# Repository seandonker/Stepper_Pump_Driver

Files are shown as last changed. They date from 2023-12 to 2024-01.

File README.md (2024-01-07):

# Stepper Pump Driver
Kicad design files and C code (adding soon) for a small PCB to control a peristaltic stepper motor pump (or any single low current bipolar stepper really).

Rendered_Board

This project was created as a cheaper alternative for fully integrated peristaltic pump solutions that tend to cost $200 or more. These stand alone units use pumps that can be had for ~$50 and lack the full programmability that this project offers through Arduino coding. While this project was meant to be used for controllings pumps (like 
[this pump here](https://www.amazon.ca/Peristaltic-Stepper-Kamoer-KPHM400-Variable/dp/B097XXJ1XD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)), it can be used for a variety of purposes where some adjustments need to be made on the fly by someone who may not know how to program/flash the arduino. This is why the design features a potentiometer and a button to change things like speed or on-time intervals. 

Component Requirements
---------------------
Apart from the provided BOM and Digikey list. The system needs a power supply, stepper motor, and the display purchased separately. 
* The power supply jack is a standard 2.1mmID x 5.5mmOD size and the supply should be rated for 12v and 3 amps or greater. 
* Bipolar stepper motor (currently selected plug socket is for a JST XHP-4 and max motor current is 1A RMS)
* The OLED display is a common 0.91" I2C with a SSD1306 chipset used in Arduino projects
* The USB differential lines were designed for a 1mm thick, 1oz top and bottom, 2-layer board (I ordered from JLPCB)

[Digikey List](https://www.digikey.ca/en/mylists/list/M6HG9QW1PJ)

Programming and Power
---------------------
The board uses the common ATMEGA328P found in some standard models of Arduinos as this allows for the use of the libraries created for the OLED screen saving a lot of time and effort. 
There is an in-circuit-serial-programming (ICSP) header to burn the arduino bootloader if the chips were purchased blank from a distributor. Then you can either continue using the header for programming or use the USB port. For the USB to work however, the USB host controller chip (FT230X) needs to be programmed through the FT_PROG utility to change one output signal of the device. Please check the schematic and the datasheet of the chip for more details. The motor driver can only be powered from the 12v source but the MCU can run from either the USB or the 12v adapter allowing for programming without the 12v supply. Both can be plugged in simultaneously without issue for serial communication for data logging or other purposes. 

Future Improvements
------------------
I would like to use a 5v regulator capable of higher input voltages (or use a DC-DC converter) so the motor controller is capable of higher speeds. With that, it would be better if the PCB has 2oz copper layers for more current and better heat sinking capabilities. This would likely require a 4-layer board however as the USB trace impedance would become hard to design. A rotary encoder would be a much better method of input too, and would be easy to implement in hardware with a 4-layer board (but would require slightly more programming).

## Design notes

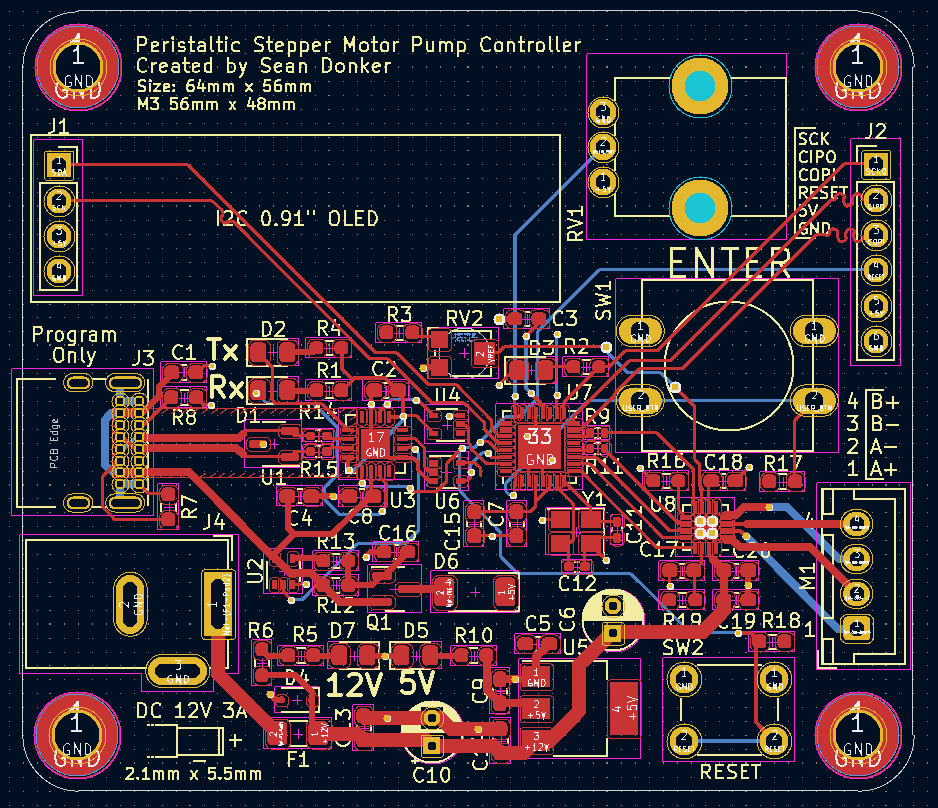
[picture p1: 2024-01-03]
PCB_Layout.png

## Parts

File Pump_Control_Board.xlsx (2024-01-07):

Source: | C:\Users\seand\Documents\KiCad\Projects\Stepper_Pump_Driver-main\Stepper_Pump_Driver-main\KiCad Files\Pump_Control_Board.kicad_sch
Date: | 2024-01-06 15:06
Tool: | Eeschema 7.0.7
Generator: | C:\Program Files\KiCad\7.0\bin\scripting\plugins/bom_csv_grouped_by_value.py
Component Count: | 70
Collated Components:
Item | Qty | Reference(s) | Value | LibPart | Footprint | Link
1 | 9 | C1, C2, C3, C7, C8, C16, C17, C18, C20 | 0.1uF | Device:C | Capacitor_SMD:C_0603_1608Metric_Pad1.08x0.95mm_HandSolder | https://www.digikey.ca/en/products/detail/samsung-electro-mechanics/CL10B104KB8NNWC/3887593
2 | 7 | C4, C5, C9, C13, C14, C15, C19 | 2.2uF | Device:C | Capacitor_SMD:C_0603_1608Metric_Pad1.08x0.95mm_HandSolder | https://www.digikey.ca/en/products/detail/samsung-electro-mechanics/CL10A225KL8NNNC/5961210
3 | 2 | C6, C10 | 100uF | Device:C_Polarized | Capacitor_THT:CP_Radial_D4.0mm_P2.00mm | https://www.digikey.ca/en/products/detail/rubycon/25PX100MEFC5X11/3134180?s=N4IgTCBcDaIIxwBwE4C0cxgCwgLoF8g
4 | 2 | C11, C12 | 15pF | Device:C_Small | Capacitor_SMD:C_0402_1005Metric_Pad0.74x0.62mm_HandSolder | https://www.digikey.ca/en/products/detail/samsung-electro-mechanics/CL05C150JB5NNNC/3886837
5 | 1 | D1 | RX_LED | Device:LED | LED_SMD:LED_0805_2012Metric_Pad1.15x1.40mm_HandSolder | https://www.digikey.ca/en/products/detail/harvatek-corporation/B1701USD-20D000114U1930/16671746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
6 | 1 | D2 | TX_LED | Device:LED | LED_SMD:LED_0805_2012Metric_Pad1.15x1.40mm_HandSolder | https://www.digikey.ca/en/products/detail/harvatek-corporation/B1701USD-20D000114U1930/16671746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
7 | 1 | D3 | MCU_LED | Device:LED | LED_SMD:LED_0805_2012Metric_Pad1.15x1.40mm_HandSolder | https://www.digikey.ca/en/products/detail/harvatek-corporation/B1701USD-20D000114U1930/16671746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
8 | 1 | D4 | SD15-01 | Device:D_Zener | Diode_SMD:D_SOD-323F | https://www.digikey.ca/en/products/detail/littelfuse-inc/SD15-01FTG/5019597?s=N4IgTCBcDaIGIDYAsSDMBhAKiAugXyA
9 | 1 | D5 | 5V_LED | Device:LED | LED_SMD:LED_0805_2012Metric_Pad1.15x1.40mm_HandSolder | https://www.digikey.ca/en/products/detail/harvatek-corporation/B1701USD-20D000114U1930/16671746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
10 | 1 | D6 | PMEG3030 | Device:D_Schottky | Diode_SMD:D_SOD-128 | https://www.digikey.ca/en/products/detail/nexperia-usa-inc/PMEG3030BEP-115/2228691
11 | 1 | D7 | 12V_LED | Device:LED | LED_SMD:LED_0805_2012Metric_Pad1.15x1.40mm_HandSolder | https://www.digikey.ca/en/products/detail/harvatek-corporation/B1701USD-20D000114U1930/16671746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
12 | 1 | F1 | Fuse | Device:Fuse | Fuse:Fuse_1206_3216Metric_Pad1.42x1.75mm_HandSolder | https://www.digikey.ca/en/products/detail/bel-fuse-inc/C1F-5/4968257
13 | 4 | H1, H2, H3, H4 | MountingHole_Pad | Mechanical:MountingHole_Pad | MountingHole:MountingHole_3.2mm_M3_ISO7380_Pad_TopBottom
14 | 1 | J1 | OLED | Connector_Generic:Conn_01x04 | Connector_PinSocket_2.54mm:PinSocket_1x04_P2.54mm_Vertical
15 | 1 | J2 | ICP Header | Connector_Generic:Conn_01x06 | Connector_PinHeader_2.54mm:PinHeader_1x06_P2.54mm_Vertical | https://www.digikey.ca/en/products/detail/sullins-connector-solutions/PPPC061LFBN-RC/810178
16 | 1 | J3 | USB_C_Receptacle_USB2.0 | Connector:USB_C_Receptacle_USB2.0 | Connector_USB:USB_C_Receptacle_GCT_USB4085 | https://www.digikey.ca/en/products/detail/gct/USB4085-GF-A/9859662?s=N4IgTCBcDaIKoGUBCAWADADgKwgLoF8g
17 | 1 | J4 | Jack | Connector:Barrel_Jack_Switch_Pin3Ring | Connector_BarrelJack:BarrelJack_GCT_DCJ200-10-A_Horizontal | https://www.digikey.ca/en/products/detail/gct/dcj200-10-a-k1-k/9859579
18 | 1 | M1 | Stepper_Motor_bipolar | Motor:Stepper_Motor_bipolar | Connector_JST:JST_XH_B4B-XH-A_1x04_P2.50mm_Vertical | https://www.digikey.ca/en/products/detail/jst-sales-america-inc/B4B-XH-A/1651047
19 | 1 | Q1 | SSM3J328R | Transistor_FET:AO3401A | Package_TO_SOT_SMD:SOT-23 | https://www.digikey.ca/en/products/detail/toshiba-semiconductor-and-storage/SSM3J328R-LF/2753199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
20 | 2 | R1, R4 | 270R | Device:R | Resistor_SMD:R_0603_1608Metric_Pad0.98x0.95mm_HandSolder | https://www.digikey.ca/en/products/detail/yageo/RC0603FR-13270RL/14286751
21 | 1 | R2 | 470R | Device:R | Resistor_SMD:R_0603_1608Metric_Pad0.98x0.95mm_HandSolder | https://www.digikey.ca/en/products/detail/yageo/RC0603FR-13470RL/13694077
22 | 1 | R3 | 10K | Device:R | Resistor_SMD:R_0603_1608Metric_Pad0.98x0.95mm_HandSolder | https://www.digikey.ca/en/products/detail/yageo/RC0603FR-0710KL/726880
23 | 1 | R5 | 1K | Device:R | Resistor_SMD:R_0603_1608Metric_Pad0.98x0.95mm_HandSolder | https://www.digikey.ca/en/products/detail/yageo/RC0603FR-0710KL/726880
24 | 2 | R6, R10 | 1K | Device:R | Resistor_SMD:R_0603_1608Metric_Pad0.98x0.95mm_HandSolder | https://www.digikey.ca/en/products/detail/yageo/RC0603FR-0710KL/726880
25 | 2 | R7, R8 | 5.1k | Device:R | Resistor_SMD:R_0603_1608Metric_Pad0.98x0.95mm_HandSolder | https://www.digikey.ca/en/products/detail/yageo/RC0603FR-135K1L/14008317
26 | 2 | R9, R11 | 0R | Device:R | Resistor_SMD:R_0402_1005Metric
27 | 1 | R12 | 91k | Device:R | Resistor_SMD:R_0603_1608Metric_Pad0.98x0.95mm_HandSolder | https://www.digikey.ca/en/products/detail/yageo/RC0603FR-0791KL/727428
28 | 1 | R13 | 1k | Device:R | Resistor_SMD:R_0603_1608Metric_Pad0.98x0.95mm_HandSolder | https://www.digikey.ca/en/products/detail/yageo/RC0603FR-0710KL/726880
29 | 2 | R14, R15 | 27R | Device:R | Resistor_SMD:R_0402_1005Metric_Pad0.72x0.64mm_HandSolder | https://www.digikey.ca/en/products/detail/yageo/RC0402FR-0727RL/5280946
30 | 2 | R16, R19 | 47K | Device:R | Resistor_SMD:R_0603_1608Metric_Pad0.98x0.95mm_HandSolder | https://www.digikey.ca/en/products/detail/yageo/RC0603JR-1347KL/13694120
31 | 2 | R17, R18 | 10k | Device:R | Resistor_SMD:R_0603_1608Metric_Pad0.98x0.95mm_HandSolder | https://www.digikey.ca/en/products/detail/yageo/RC0603FR-0710KL/726880
32 | 1 | RV1 | POT | Device:R_Potentiometer | Potentiometer_THT:Potentiometer_Bourns_PTV09A-1_Single_Vertical | https://www.digikey.ca/en/products/detail/bourns-inc/PTV09A-4220U-B103/3781152
33 | 1 | RV2 | Trimmer_10K | Device:R_Potentiometer | Potentiometer_SMD:Potentiometer_Bourns_TC33X_Vertical | https://www.digikey.ca/en/products/detail/bourns-inc/TC33X-2-103E/612858
34 | 1 | SW1 | SW_USER | Switch:SW_Push | Button_Switch_THT:SW_PUSH-12mm | https://www.digikey.ca/en/products/detail/cui-devices/TS14-1212-43-BK-160-SCR-D/16562768
35 | 1 | SW2 | SW_RESET | Switch:SW_Push | Button_Switch_THT:SW_PUSH_6mm | https://www.digikey.ca/en/products/detail/cui-devices/TS02-66-50-BK-260-SCR-D/15634296
36 | 1 | U1 | ESDALD05 | Donker_Custom:ESDALD05 | Package_TO_SOT_SMD:SOT-23-3 | https://www.digikey.ca/en/products/detail/ween-semiconductors/ESDALD05UE2X/15775762
37 | 3 | U2, U4, U6 | SN74LV1T34DCK | Logic_LevelTranslator:SN74LV1T34DCK | Package_TO_SOT_SMD:SOT-353_SC-70-5 | https://www.digikey.ca/en/products/detail/texas-instruments/SN74LV1T34DCKR/4555576
38 | 1 | U3 | FT230XQ | Interface_USB:FT230XQ | Package_DFN_QFN:QFN-16-1EP_4x4mm_P0.65mm_EP2.1x2.1mm | https://www.digikey.ca/en/products/detail/ftdi-future-technology-devices-international-ltd/FT230XQ-R/3029142
39 | 1 | U5 | LM1117DT-5.0 | Regulator_Linear:LM1117DT-5.0 | Package_TO_SOT_SMD:SOT-223 | https://www.digikey.ca/en/products/detail/onsemi/NCP1117LPST50T3G/2194022
40 | 1 | U7 | ATmega328P-M | MCU_Microchip_ATmega:ATmega328P-M | Package_DFN_QFN:QFN-32-1EP_5x5mm_P0.5mm_EP3.1x3.1mm | https://www.digikey.ca/en/products/detail/microchip-technology/ATMEGA328PB-MU/5638814
41 | 1 | U8 | DRV8428_WQFN | Donker_Custom:DRV8428_WQFN | Package_DFN_QFN:WQFN-16-1EP_3x3mm_P0.5mm_EP1.68x1.68mm | https://www.digikey.ca/en/products/detail/texas-instruments/DRV8428RTER/13687809
42 | 1 | Y1 | 16MHz | Device:Crystal_GND24_Small | Crystal:Crystal_SMD_3225-4Pin_3.2x2.5mm | https://www.digikey.ca/en/products/detail/raltron-electronics/RH100-16-000-12-1010-EXT-TR/10272690

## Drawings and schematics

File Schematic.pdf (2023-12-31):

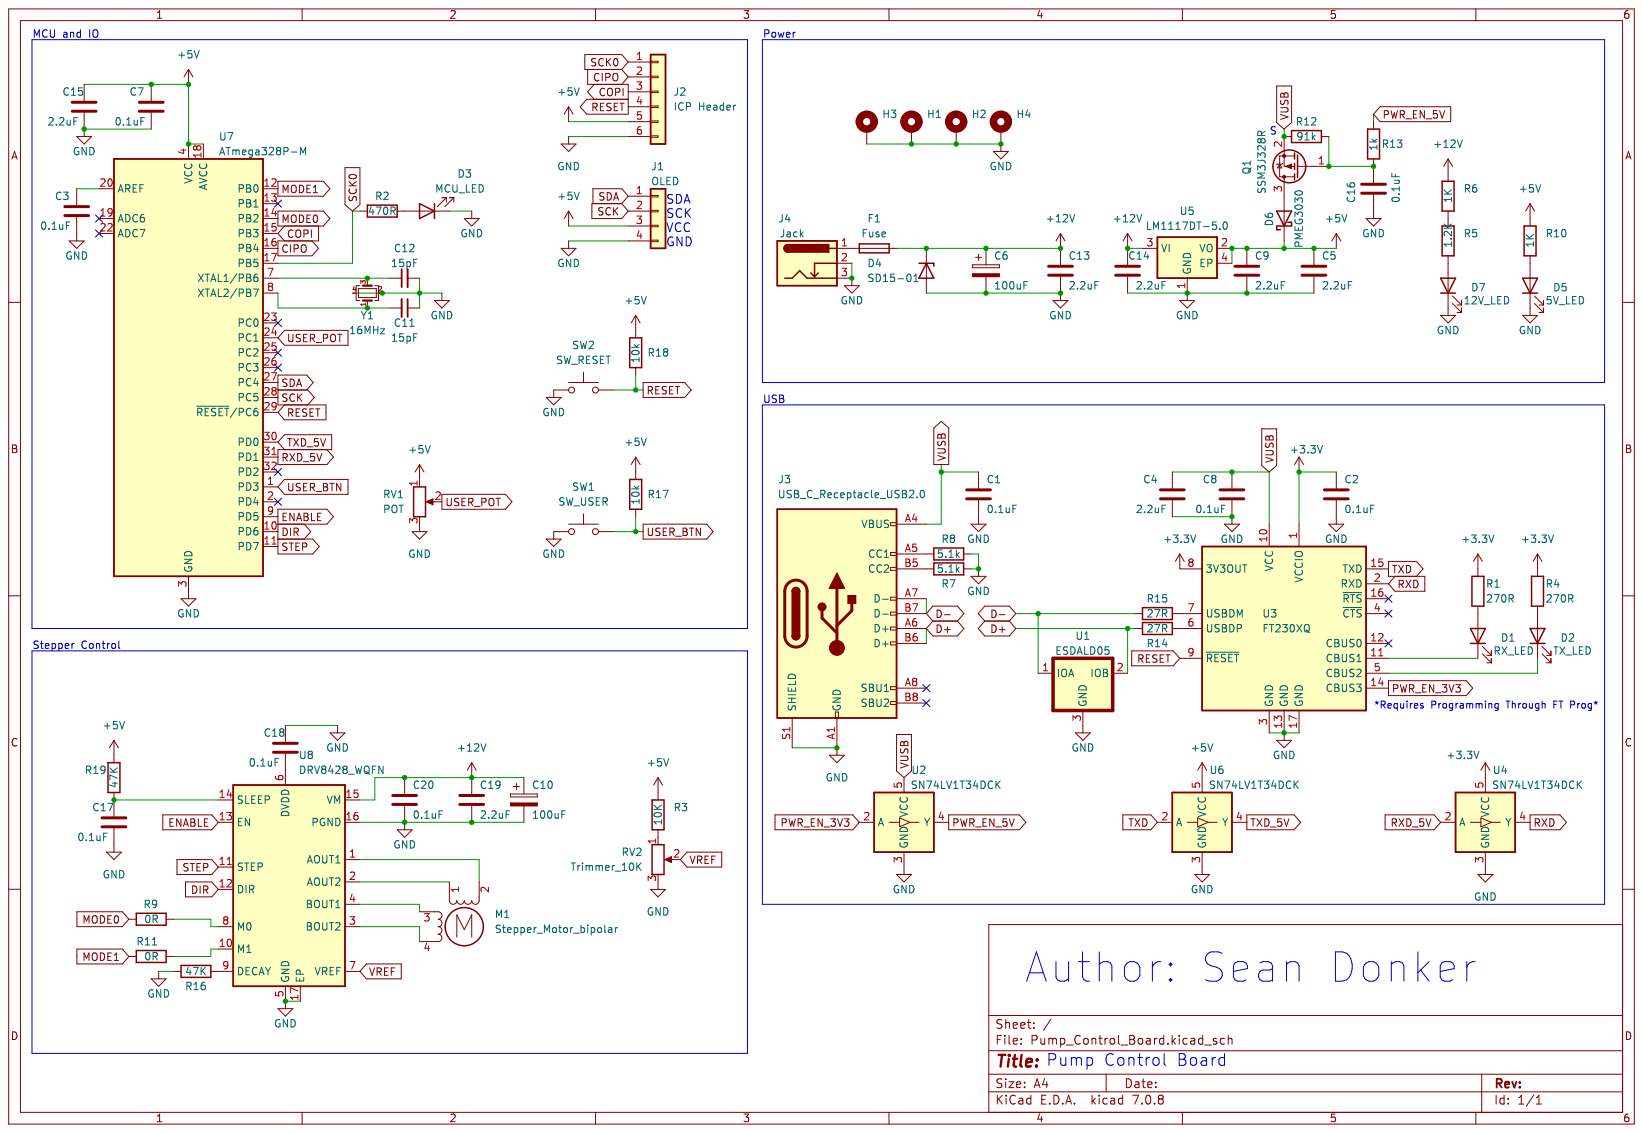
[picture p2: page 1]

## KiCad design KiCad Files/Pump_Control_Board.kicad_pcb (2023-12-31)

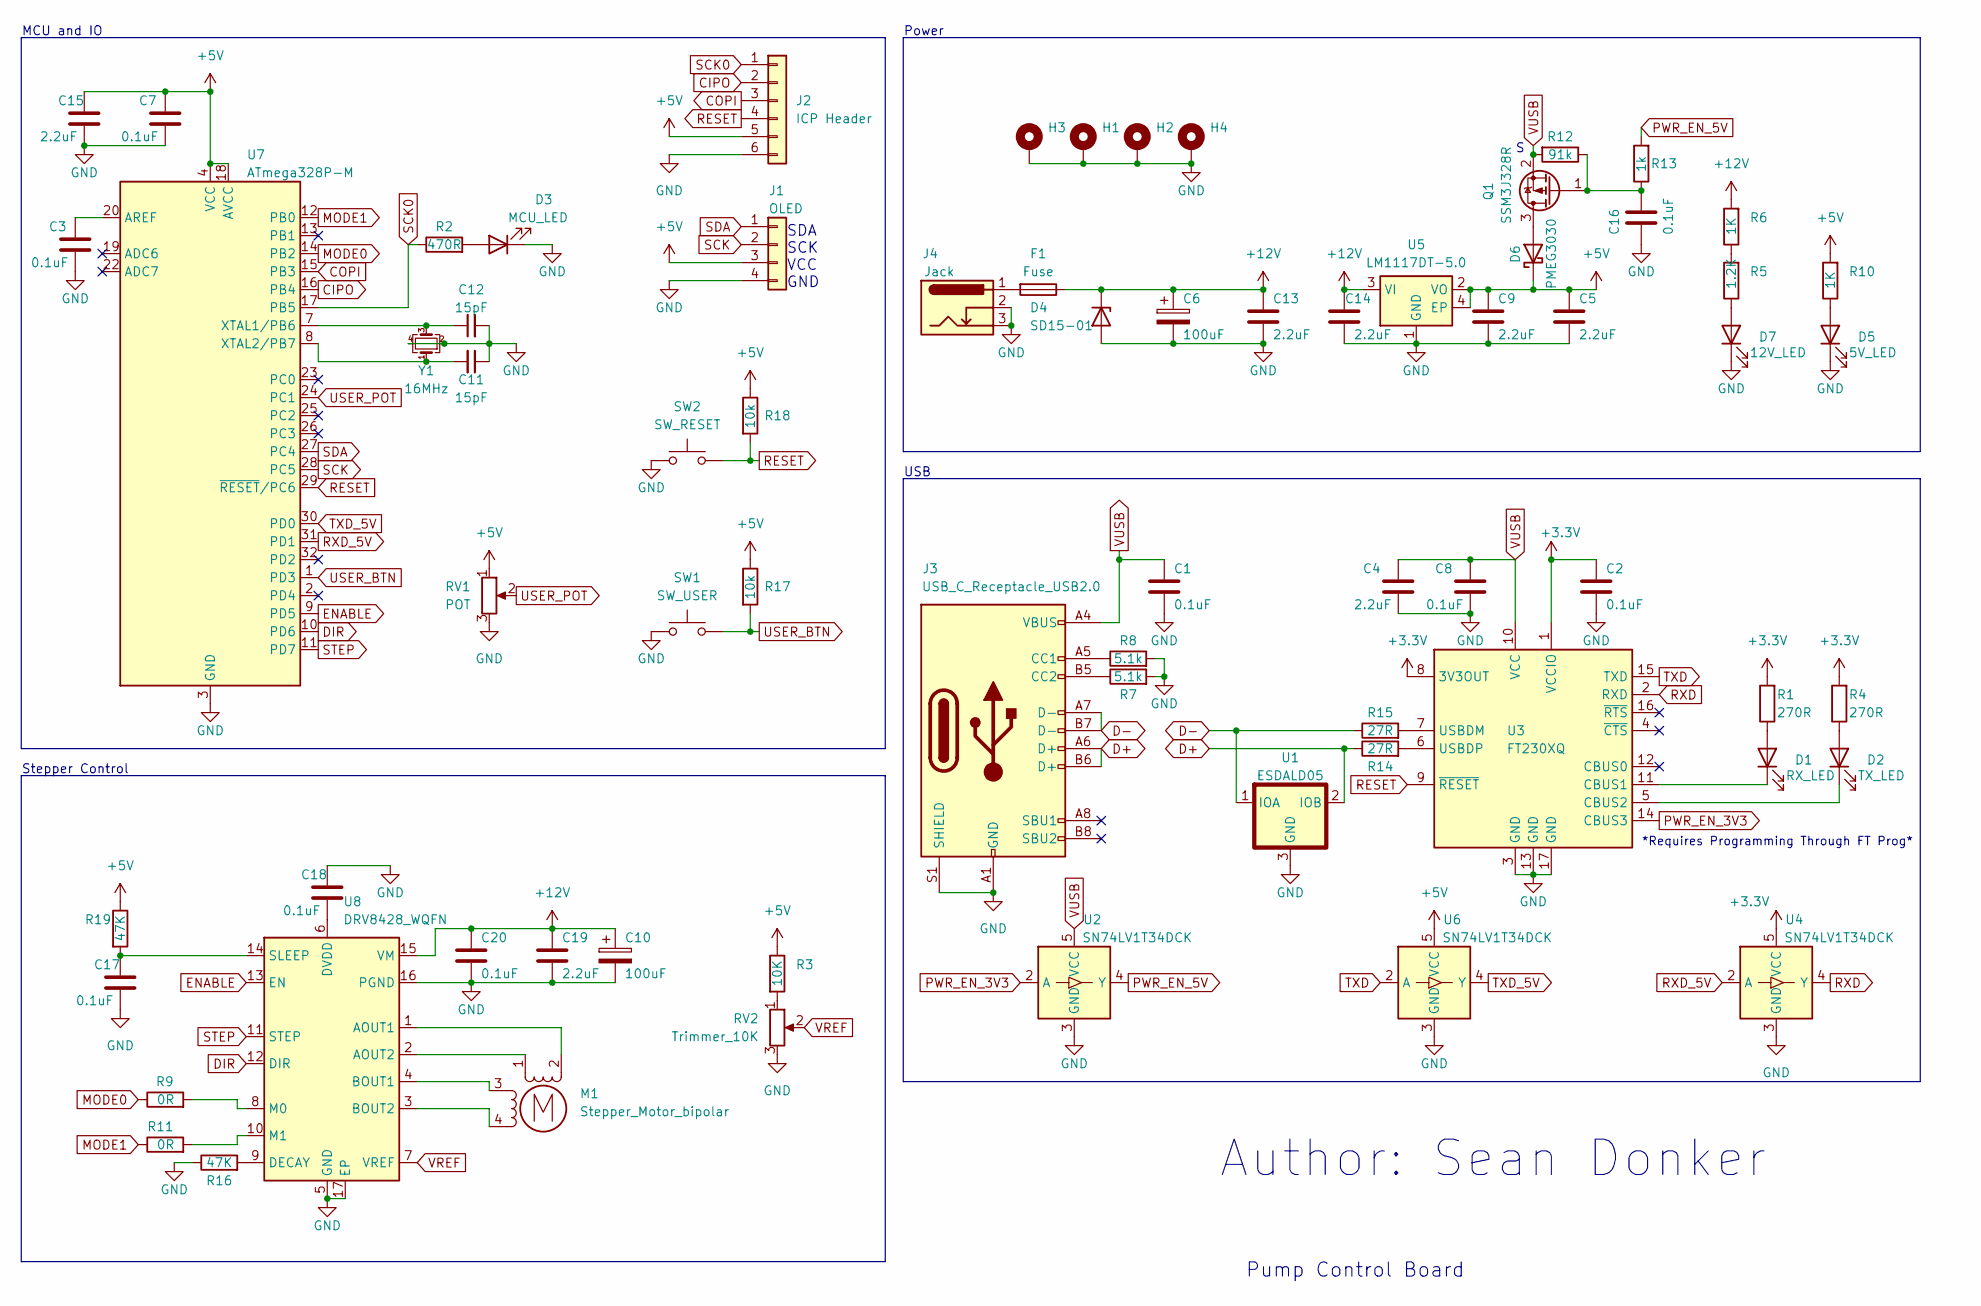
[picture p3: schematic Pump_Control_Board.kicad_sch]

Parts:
C1, C2, C3, C7, C8, C16, C17, C18, C20: 0.1uF; C_0603_1608Metric_Pad1.08x0.95mm_HandSolder
C4, C5, C9, C13, C14, C15, C19: 2.2uF; C_0603_1608Metric_Pad1.08x0.95mm_HandSolder
C6, C10: 100uF; CP_Radial_D4.0mm_P2.00mm
C11, C12: 15pF; C_0402_1005Metric_Pad0.74x0.62mm_HandSolder
D1: RX_LED; LED_0805_2012Metric_Pad1.15x1.40mm_HandSolder
D2: TX_LED; LED_0805_2012Metric_Pad1.15x1.40mm_HandSolder
D3: MCU_LED; LED_0805_2012Metric_Pad1.15x1.40mm_HandSolder
D4: SD15-01; D_SOD-323F
D5: 5V_LED; LED_0805_2012Metric_Pad1.15x1.40mm_HandSolder
D6: PMEG3030; D_SOD-128
D7: 12V_LED; LED_0805_2012Metric_Pad1.15x1.40mm_HandSolder
F1: Fuse; Fuse_1206_3216Metric_Pad1.42x1.75mm_HandSolder
H1, H2, H3, H4: MountingHole_Pad; MountingHole_3.2mm_M3_ISO7380_Pad_TopBottom
J1: OLED; PinSocket_1x04_P2.54mm_Vertical
J2: ICP Header; PinHeader_1x06_P2.54mm_Vertical
J3: USB_C_Receptacle_USB2.0; USB_C_Receptacle_GCT_USB4085
J4: Jack; BarrelJack_GCT_DCJ200-10-A_Horizontal
M1: Stepper_Motor_bipolar; JST_XH_B4B-XH-A_1x04_P2.50mm_Vertical
Q1: SSM3J328R; SOT-23
R1, R4: 270R; R_0603_1608Metric_Pad0.98x0.95mm_HandSolder
R2: 470R; R_0603_1608Metric_Pad0.98x0.95mm_HandSolder
R3: 10K; R_0603_1608Metric_Pad0.98x0.95mm_HandSolder
R5: 1.2K; R_0603_1608Metric_Pad0.98x0.95mm_HandSolder
R6, R10: 1K; R_0603_1608Metric_Pad0.98x0.95mm_HandSolder
R7, R8: 5.1k; R_0603_1608Metric_Pad0.98x0.95mm_HandSolder
R9, R11: 0R; R_0402_1005Metric
R12: 91k; R_0603_1608Metric_Pad0.98x0.95mm_HandSolder
R13: 1k; R_0603_1608Metric_Pad0.98x0.95mm_HandSolder
R14, R15: 27R; R_0402_1005Metric_Pad0.72x0.64mm_HandSolder
R16, R19: 47K; R_0603_1608Metric_Pad0.98x0.95mm_HandSolder
R17, R18: 10k; R_0603_1608Metric_Pad0.98x0.95mm_HandSolder
RV1: POT; Potentiometer_Bourns_PTV09A-1_Single_Vertical
RV2: Trimmer_10K; Potentiometer_Bourns_TC33X_Vertical
SW1: SW_USER; SW_PUSH-12mm
SW2: SW_RESET; SW_PUSH_6mm
U1: ESDALD05; SOT-23-3
U2, U4, U6: SN74LV1T34DCK; SOT-353_SC-70-5
U3: FT230XQ; QFN-16-1EP_4x4mm_P0.65mm_EP2.1x2.1mm
U5: LM1117DT-5.0; SOT-223
U7: ATmega328P-M; QFN-32-1EP_5x5mm_P0.5mm_EP3.1x3.1mm
U8: DRV8428_WQFN; WQFN-16-1EP_3x3mm_P0.5mm_EP1.68x1.68mm
Y1: 16MHz; Crystal_SMD_3225-4Pin_3.2x2.5mm

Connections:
+3.3V: C2.1, R1.2, R4.2, U3.1 (VCCIO), U3.8 (3V3OUT), U4.5 (VCC)
+5V: C5.1, C7.1, C9.1, C15.1, D6.1 (K), J1.3, J2.5, R3.1, R10.2, R17.1, R18.1, R19.1, RV1.1, U5.2 (VO), U5.4 (EP), U6.5 (VCC), U7.4 (VCC), U7.6 (VCC), U7.18 (AVCC)
+12V: C6.1, C10.1, C13.1, C14.1, C19.1, C20.1, D4.1 (K), F1.1, R6.2, U5.3 (VI), U8.15 (VM)
CIPO: J2.2, U7.16 (PB4)
COPI: J2.3, U7.15 (PB3)
D+: J3.A6 (D+), J3.B6 (D+), R14.1, U1.2 (IOB)
D-: J3.A7 (D-), J3.B7 (D-), R15.1, U1.1 (IOA)
DIR: U7.10 (PD6), U8.12 (DIR)
ENABLE: U7.9 (PD5), U8.13 (EN)
GND: C1.2, C2.2, C3.2, C4.2, C5.2, C6.2, C7.2, C8.2, C9.2, C10.2, C11.1, C12.2, C13.2, C14.2, C15.2, C16.2, C17.2, C18.1, C19.2, C20.2, D3.1 (K), D4.2 (A), D5.1 (K), D7.1 (K), H1.1, H2.1, H3.1, H4.1, J1.4, J2.6, J3.A1 (GND), J3.A12 (GND), J3.B1 (GND), J3.B12 (GND), J3.S1 (SHIELD), J4.2, J4.3, R7.2, R8.2, R16.1, RV1.3, RV2.3, SW1.1, SW2.1, U1.3 (GND), U2.3 (GND), U3.3 (GND), U3.13 (GND), U3.17 (GND), U4.3 (GND), U5.1 (GND), U6.3 (GND), U7.3 (GND), U7.5 (GND), U7.21 (GND), U7.33 (GND), U8.5 (GND), U8.16 (PGND), U8.17 (EP), Y1.2, Y1.4
MODE0: R9.1, U7.14 (PB2)
MODE1: R11.1, U7.12 (PB0)
unnamed: D1.2 (A), R1.1
unnamed: D1.1 (K), U3.11 (CBUS1)
unnamed: D2.2 (A), R4.1
unnamed: D2.1 (K), U3.5 (CBUS2)
unnamed: D3.2 (A), R2.2
unnamed: D5.2 (A), R10.1
unnamed: D6.2 (A), Q1.3 (D)
unnamed: D7.2 (A), R5.1
unnamed: F1.2, J4.1
unnamed: J3.A5 (CC1), R8.1
unnamed: J3.B5 (CC2), R7.1
unnamed: M1.2 (-), U8.1 (AOUT1)
unnamed: C16.1, Q1.1 (G), R12.1, R13.1
unnamed: R3.2, RV2.1
unnamed: R5.2, R6.1
unnamed: R15.2, U3.7 (USBDM)
unnamed: R14.2, U3.6 (USBDP)
unnamed: C3.1, U7.20 (AREF)
unnamed: C12.1, U7.7 (XTAL1/PB6), Y1.3
unnamed: C11.2, U7.8 (XTAL2/PB7), Y1.1
unnamed: M1.1, U8.2 (AOUT2)
unnamed: M1.3, U8.4 (BOUT1)
unnamed: M1.4, U8.3 (BOUT2)
unnamed: R16.2, U8.9 (DECAY)
unnamed: C18.2, U8.6 (DVDD)
unnamed: R9.2, U8.8 (M0)
unnamed: R11.2, U8.10 (M1)
unnamed: C17.1, R19.2, U8.14 (SLEEP)
PWR_EN_3V3: U2.2 (A), U3.14 (CBUS3)
PWR_EN_5V: R13.2, U2.4 (Y)
RESET: J2.4, R18.2, SW2.2, U3.9 (~RESET), U7.29 (~RESET/PC6)
RXD: U3.2 (RXD), U4.4 (Y)
RXD_5V: U4.2 (A), U7.31 (PD1)
SCK: J1.2, U7.28 (PC5)
SCK0: J2.1, R2.1, U7.17 (PB5)
SDA: J1.1, U7.27 (PC4)
STEP: U7.11 (PD7), U8.11 (STEP)
TXD: U3.15 (TXD), U6.2 (A)
TXD_5V: U6.4 (Y), U7.30 (PD0)
USER_BTN: R17.2, SW1.2, U7.1 (PD3)
USER_POT: RV1.2, U7.24 (PC1)
VREF: RV2.2, U8.7 (VREF)
VUSB: C1.1, C4.1, C8.1, J3.A4 (VBUS), J3.A9 (VBUS), J3.B4 (VBUS), J3.B9 (VBUS), Q1.2 (S), R12.2, U2.5 (VCC), U3.10 (VCC)

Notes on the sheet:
Author: Sean Donker
SDA SCK VCC GND
USB
MCU and IO
Stepper Control
Power
Pump Control Board
*Requires Programming Through FT Prog*

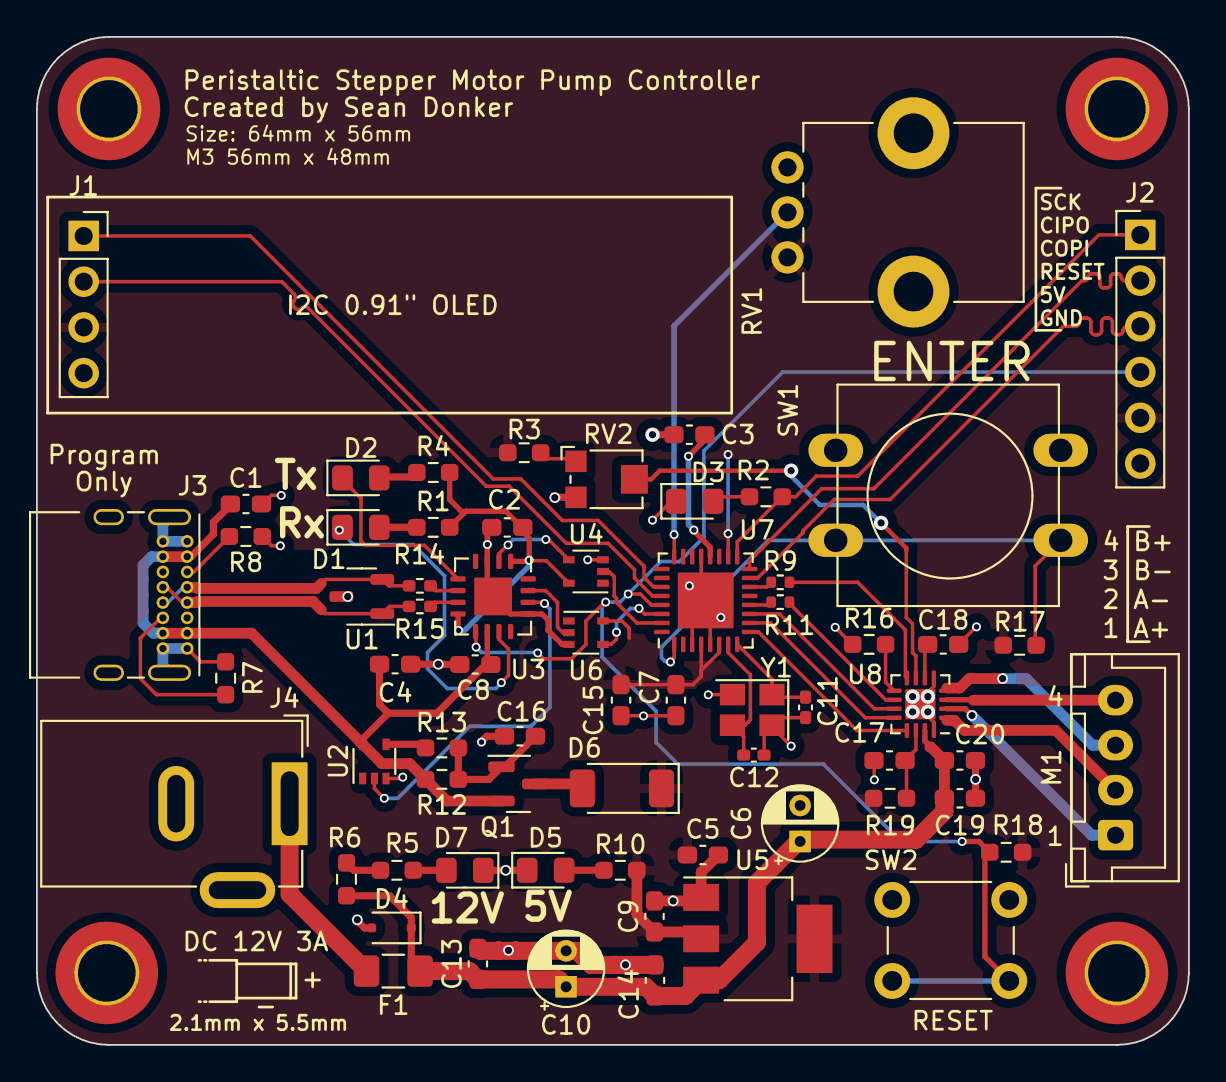
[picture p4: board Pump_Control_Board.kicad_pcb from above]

Board: 2 copper layers, 64.0 x 56.0 mm, 70 parts (0 on the bottom side), 55 nets.

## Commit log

2023-12-31 PCB File Add
    [Pump_Control_Board-B_Cu.gbl, Pump_Control_Board-B_Mask.gbs, Pump_Control_Board-B_Paste.gbp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]
2023-12-31 Named ICP Header
    [Pump_Control_Board.kicad_pcb, Pump_Control_Board.kicad_sch]
2024-01-03 added pcb layout pic
2024-01-07 added BOM
    [Pump_Control_Board.xlsx]
